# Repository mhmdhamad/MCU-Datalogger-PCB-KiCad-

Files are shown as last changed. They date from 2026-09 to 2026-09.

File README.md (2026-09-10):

# MCU Datalogger — KiCad PCB Project

An MCU-based datalogger board designed in KiCad 9, featuring a real-time clock (DS1337S) and onboard memory, built around an ATmega328P-AU.

## Branches

This repository uses branches to track different hardware revisions of the same design:

| Branch | Description |
|---|---|
| `main` | Primary development branch |
| `2layer`  | 2-layer PCB variant |
| `4layer`  | 4-layer PCB variant (dedicated ground/power planes) |

Each branch contains its own schematic and PCB layout for that board revision. Gerbers for each variant are generated and stored per-branch.

## Features

- ATmega328P-AU microcontroller
- DS1337S real-time clock
- GPIO and serial header breakouts
- Designed and routed in KiCad 9.0

## Getting Started

1. Clone the repository:
   ```
   git clone https://github.com/mhmdhamad/MCU-Datalogger-PCB-KiCad-.git
   ```
2. Check out the branch for the board revision you want:
   ```
   git checkout 2layer
   ```
3. Open `MCU Datalogger.kicad_pro` in KiCad 9.0 or later.

## License

This project is licensed under the [CERN Open Hardware Licence Version 2 - Strongly Reciprocal (CERN-OHL-S)](LICENSE). You are free to use, study, modify, and manufacture this design, provided that any distributed modifications are released under the same license.

## Author

Mohammad — MSc Electronics Engineering, Lebanese International University

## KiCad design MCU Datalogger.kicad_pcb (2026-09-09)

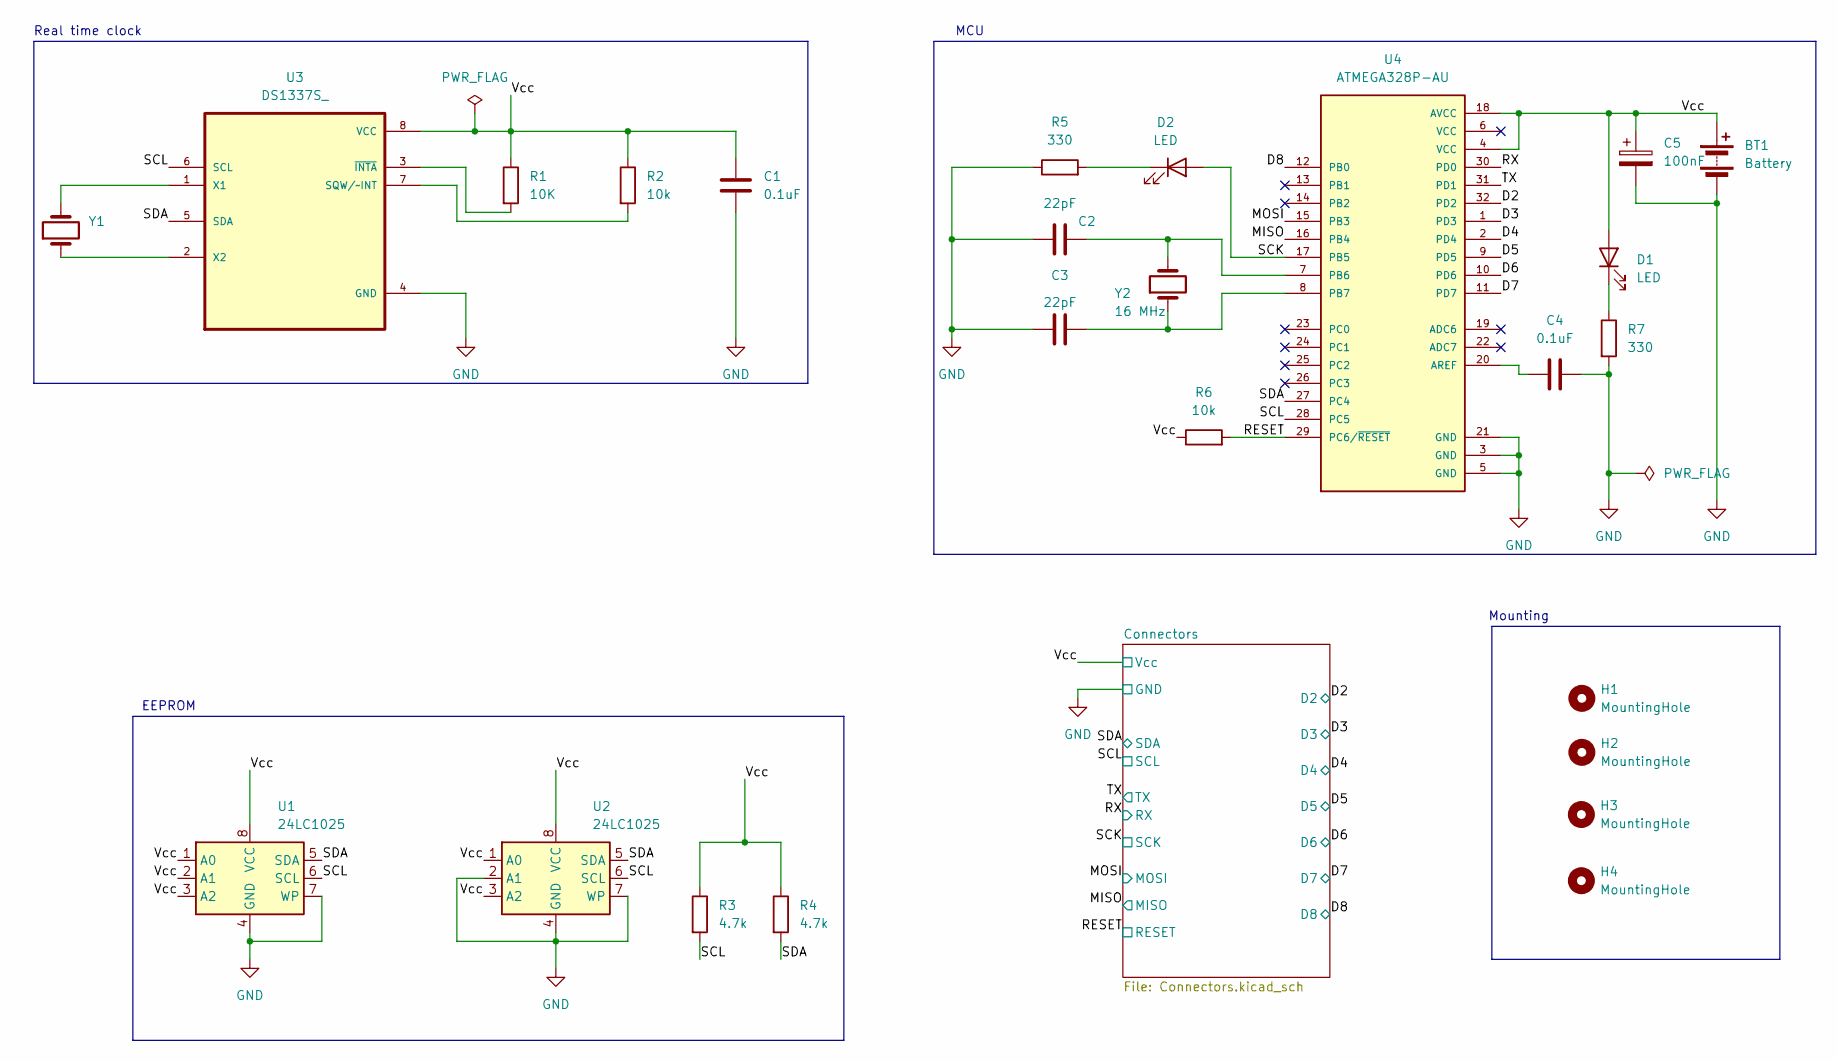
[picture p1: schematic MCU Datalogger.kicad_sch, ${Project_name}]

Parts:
BT1: Battery; PinHeader_1x02_P2.54mm_Vertical
C1, C4: 0.1uF; C_0805_2012Metric
C2, C3: 22pF; C_0805_2012Metric
C5: 100nF; C_0805_2012Metric
D1, D2: LED; LED_0805_2012Metric
H1, H2, H3, H4: MountingHole; MountingHole_2.1mm
R1: 10K; R_0805_2012Metric
R2, R6: 10k; R_0805_2012Metric
R3, R4: 4.7k; R_0805_2012Metric
R5, R7: 330; R_0805_2012Metric
U1, U2: 24LC1025; SOIC-8_5.3x5.3mm_P1.27mm
U3: DS1337S_; SOIC127P600X175-8N
U4: ATMEGA328P-AU; QFP80P900X900X120-32N; PARTREV 8271A
Y1: 32.768 KHz; Crystal_SMD_5032-2Pin_5.0x3.2mm
Y2: 16 MHz; Crystal_SMD_5032-2Pin_5.0x3.2mm

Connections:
/D2: U4.32 (PD2); also elsewhere on the board
/D3: U4.1 (PD3); also elsewhere on the board
/D4: U4.2 (PD4); also elsewhere on the board
/D5: U4.9 (PD5); also elsewhere on the board
/D6: U4.10 (PD6); also elsewhere on the board
/D7: U4.11 (PD7); also elsewhere on the board
/D8: U4.12 (PB0); also elsewhere on the board
/MISO: U4.16 (PB4); also elsewhere on the board
/MOSI: U4.15 (PB3); also elsewhere on the board
/RESET: R6.2, U4.29 (PC6/~RESET); also elsewhere on the board
/RX: U4.30 (PD0); also elsewhere on the board
/SCK: D2.2 (A), U4.17 (PB5); also elsewhere on the board
/SCL: R3.2, U1.6 (SCL), U2.6 (SCL), U3.6 (SCL), U4.28 (PC5); also elsewhere on the board
/SDA: R4.2, U1.5 (SDA), U2.5 (SDA), U3.5 (SDA), U4.27 (PC4); also elsewhere on the board
/TX: U4.31 (PD1); also elsewhere on the board
/Vcc: BT1.1 (+), C1.1, C5.1, D1.2 (A), R1.1, R2.1, R3.1, R4.1, R6.1, U1.1 (A0), U1.2 (A1), U1.3 (A2), U1.8 (VCC), U2.1 (A0), U2.3 (A2), U2.8 (VCC), U3.8 (VCC), U4.4 (VCC), U4.18 (AVCC); also elsewhere on the board
GND: BT1.2 (-), C1.2, C2.1, C3.1, C4.2, C5.2, R5.1, R7.2, U1.4 (GND), U1.7 (WP), U2.2 (A1), U2.4 (GND), U2.7 (WP), U3.4 (GND), U4.3 (GND), U4.5 (GND), U4.21 (GND); also elsewhere on the board
unnamed: D1.1 (K), R7.1
unnamed: D2.1 (K), R5.2
unnamed: R2.2, U3.7 (SQW/~INT)
unnamed: U3.1 (X1), Y1.2
unnamed: U3.2 (X2), Y1.1
unnamed: R1.2, U3.3 (~INTA)
unnamed: C4.1, U4.20 (AREF)
unnamed: C2.2, U4.7 (PB6), Y2.2
unnamed: C3.2, U4.8 (PB7), Y2.1

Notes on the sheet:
EEPROM
Mounting
MCU
Real time clock

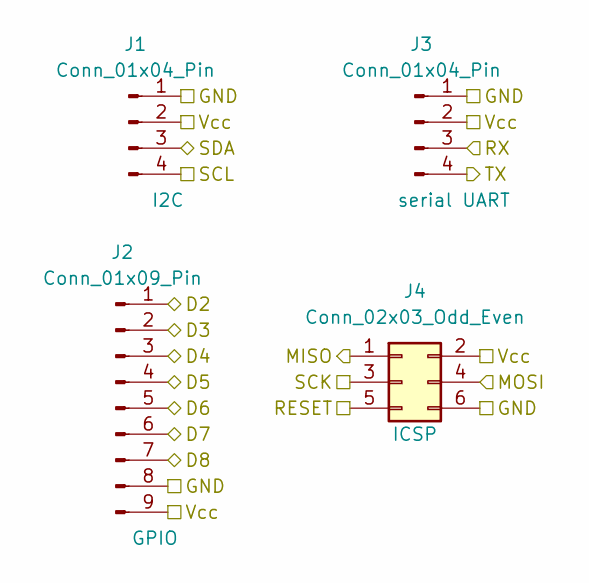
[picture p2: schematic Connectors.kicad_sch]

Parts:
J1, J3: Conn_01x04_Pin; PinHeader_1x04_P2.54mm_Vertical
J2: Conn_01x09_Pin; PinHeader_1x09_P2.54mm_Vertical
J4: Conn_02x03_Odd_Even; PinHeader_2x03_P2.54mm_Vertical

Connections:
/D2: J2.1; also elsewhere on the board
/D3: J2.2; also elsewhere on the board
/D4: J2.3; also elsewhere on the board
/D5: J2.4; also elsewhere on the board
/D6: J2.5; also elsewhere on the board
/D7: J2.6; also elsewhere on the board
/D8: J2.7; also elsewhere on the board
/MISO: J4.1; also elsewhere on the board
/MOSI: J4.4; also elsewhere on the board
/RESET: J4.5; also elsewhere on the board
/RX: J3.3; also elsewhere on the board
/SCK: J4.3; also elsewhere on the board
/SCL: J1.4; also elsewhere on the board
/SDA: J1.3; also elsewhere on the board
/TX: J3.4; also elsewhere on the board
/Vcc: J1.2, J2.9, J3.2, J4.2; also elsewhere on the board
GND: J1.1, J2.8, J3.1, J4.6; also elsewhere on the board

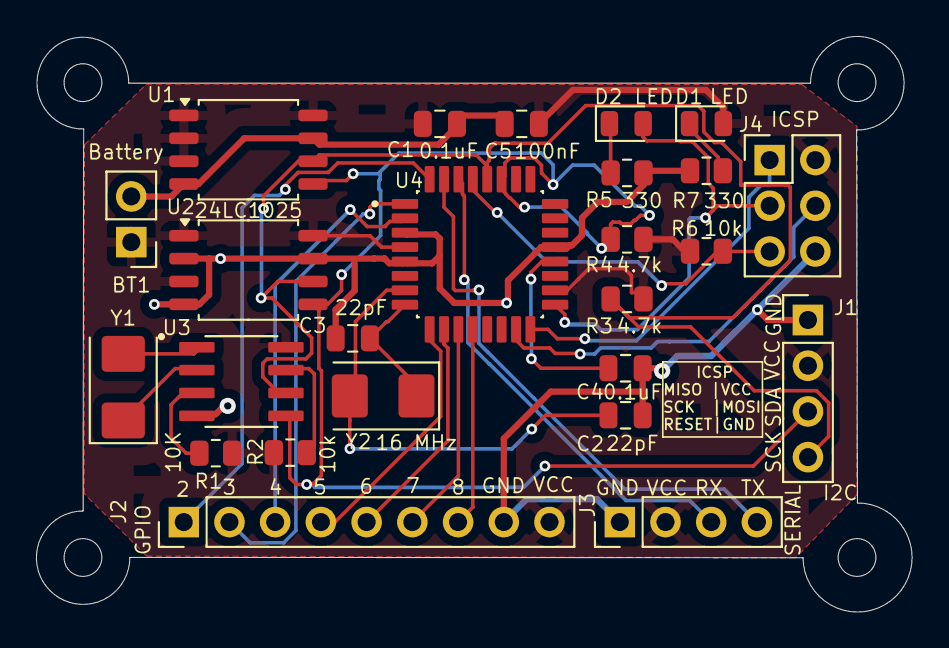
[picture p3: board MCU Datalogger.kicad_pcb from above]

Board: 2 copper layers, 48.6 x 32.0 mm, 29 parts (0 on the bottom side), 26 nets.

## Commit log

2026-09-06 Changed location of symbols (arrange).
    [Connectors.kicad_sch, MCU Datalogger.kicad_sch]
2026-09-06 edit component values
    [MCU Datalogger.kicad_sch]
2026-09-06 completed symbol-footprint assiciations
    [Connectors.kicad_sch, MCU Datalogger.kicad_sch]
2026-09-06 completed wiring of main sheet.
    [MCU Datalogger.kicad_sch]
2026-09-06 completed wiring in the second sheet.
    [Connectors.kicad_sch, MCU Datalogger.kicad_sch]
2026-09-06 Aallocated GND and Vcc nets to the Power net class.
2026-09-06 completed commets.
    [MCU Datalogger.kicad_sch]
2026-09-07 setup PCBnew
    [MCU Datalogger.kicad_pcb]
2026-09-07 adding footprints for PCBnew with arrangment.
    [MCU Datalogger.kicad_pcb]
2026-09-07 Routing sans GNC VCC complete.
    [MCU Datalogger.kicad_pcb]
2026-09-07 finish routing with filling zones/
    [MCU Datalogger.kicad_pcb]
2026-09-08 the final editing on routing.
    [MCU Datalogger.kicad_pcb]
2026-09-08 finshing silkscreen.
    [Connectors.kicad_sch, MCU Datalogger.kicad_sch]
2026-09-08 ready to manufacturing
    [MCU Datalogger.kicad_pcb]
2026-09-08 adding the 3D modeles for components.
    [MCU Datalogger.kicad_pcb]
2026-09-09 added the gerber files.
    [MCU Datalogger.kicad_pcb]
2026-09-09 ready to merge to the main branch.
    [MCU Datalogger-B_Cu.gbr, MCU Datalogger-B_Mask.gbr, MCU Datalogger-B_Paste.gbr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]
2026-09-09 modified getignre and remove gerbers.
    [MCU Datalogger-B_Cu.gbr, MCU Datalogger-B_Mask.gbr, MCU Datalogger-B_Paste.gbr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]
2026-09-09 completed 4Layer PCB routing.
    [MCU Datalogger.kicad_pcb]
2026-09-09 added board characteristics.
    [MCU Datalogger.kicad_pcb]
2026-09-09 added gitattributes file to ignore PCB files during merge.
2026-09-09 make some edeting on schematic to test gitattributes.
    [MCU Datalogger.kicad_sch]
2026-09-09 another schematic change for testing
    [MCU Datalogger.kicad_sch]
2026-09-09 fix the bugs in the schematic.
    [Connectors.kicad_sch, MCU Datalogger.kicad_sch]
2026-09-09 restore 2-layer PCB layout on main
    [MCU Datalogger.kicad_pcb]
2026-09-09 fixing pcb routing after fix the schematic.
    [MCU Datalogger.kicad_pcb]
2026-09-09 added board characteristics for 2 layer pcb.
    [MCU Datalogger.kicad_pcb]
